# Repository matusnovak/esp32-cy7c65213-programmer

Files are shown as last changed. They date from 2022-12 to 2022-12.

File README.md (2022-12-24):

# ESP32 USB-C programmer with CY7C65213

This is a simple USB-C programmer that uses the CY7C65213 UART bridge controller. This repository contains KiCad 6 project files with gerber files exported. This board is capable of DTR and RTS, therefore the program upload experience should be without any problem.

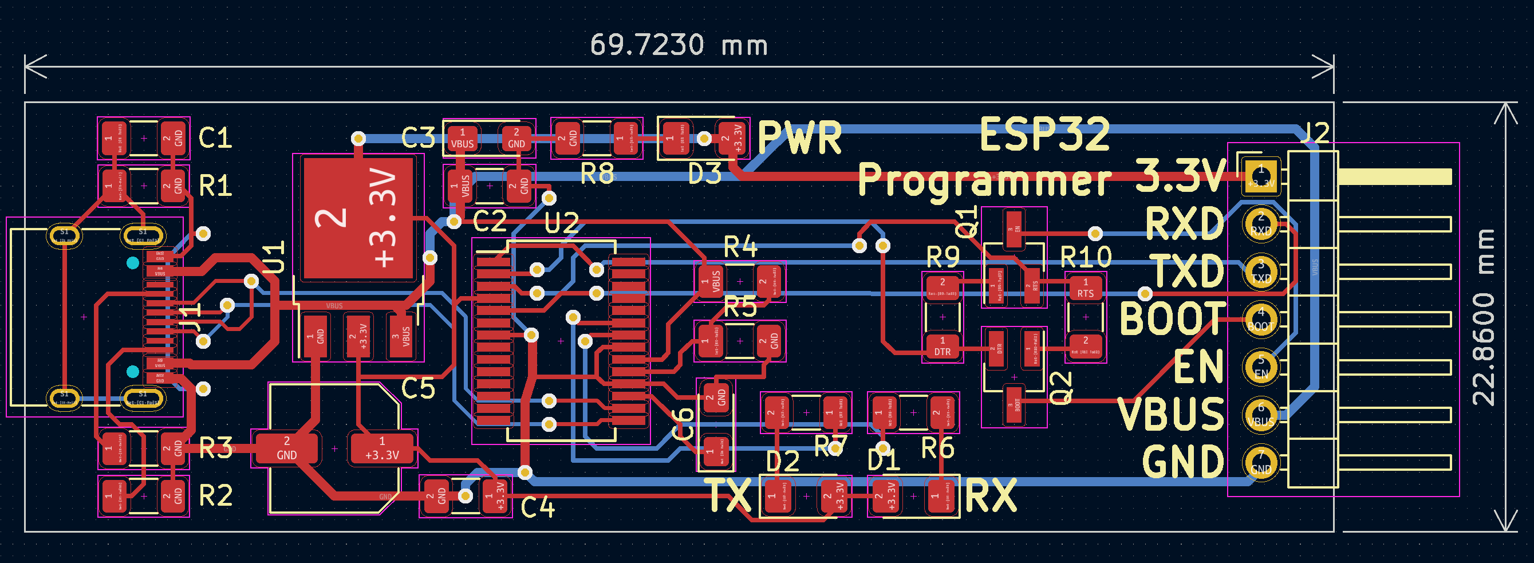
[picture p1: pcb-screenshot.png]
Board image


**[Schematic PDF](esp32-cy7c65213-programmer.pdf)**

## NOTE

* Do not connect a capacitor on the BOOT pin (GPIO 0 pin) towards the ground. It will cause the ESP32 to jump to the programming mode on power up.
* Use 1uF capacitor between the ESP32 reset pin (also known as EN or PN pin) between it and the ground. You will also need 10K pull-up resistor between that same reset pin and the + 3.3V.
* The Rx, Tx, Boot, and En pins on this board are 3.3V tolerant only.
* The Rx LED may start blinking or stay up. This is due to Rx picking up noise and treating it as a signal if nothing is connected to the Rx.

## Connection schematic

Use the following schematic to connect this programmer to ESP32

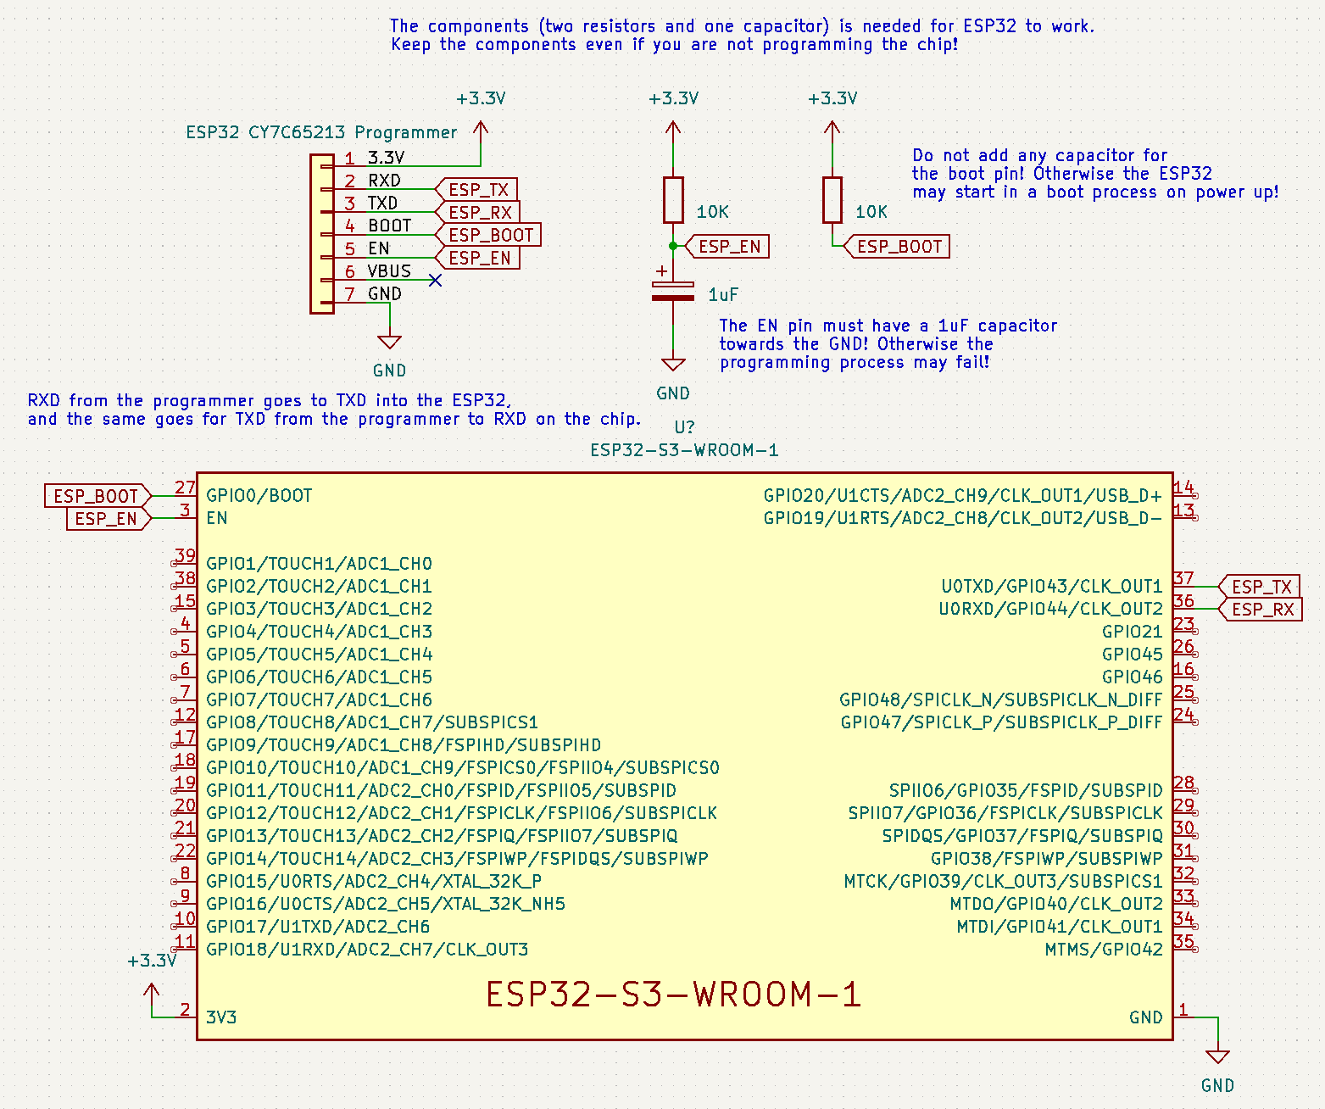
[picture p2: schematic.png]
schematic


## Drivers

* Windows: [Link to the manufacturer Infineon](https://www.infineon.com/cms/en/design-support/tools/sdk/usb-controllers-sdk/usb-serial-software-development-kit/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)
* Linux: Works out of the box, no driver needed, any recent Kernel is fine, it will appear at `/dev/ttyACM0`.
* MacOS: Should work out of the box.

## Why CY7C65213?

It works in Linux out of the box without the need to install any drivers (it needs a driver on Windows). Compared to the CH340 UART controller, the drivers for CY7C65213 are stable and mature. I do not want to install some shady CH340 drivers that work half of the time and randomly disconnect.

## Programming (platformio)

If you are using platformio for programming, you can use the following example below:

```ini
[env:esp32s3]
platform = espressif32        # Required
board = adafruit_feather_esp32s3_nopsram # Required, or choose similar
framework = espidf            # Or "arduino", your choice.
upload_port = /dev/ttyACM0    # Or COM3 or similar for Windows
board_build.flash_mode = dio  # Might be needed for a successful upload to ESP32-S3
monitor_port = /dev/ttyACM0   # Or COM3 or similar for Windows
monitor_speed = 115200        # This is the default value
```

## Programming (Arduino)

Simply choose the correct COM port from the top menu bar, and use the Adafruit Feather ESP32 board. (It should work with any board).

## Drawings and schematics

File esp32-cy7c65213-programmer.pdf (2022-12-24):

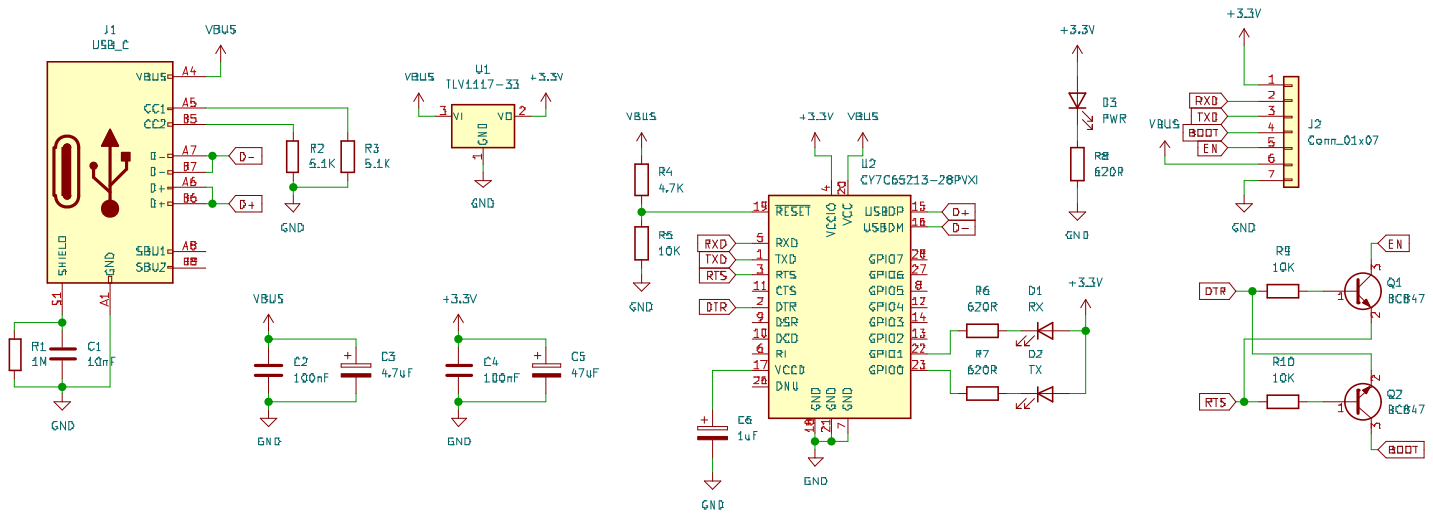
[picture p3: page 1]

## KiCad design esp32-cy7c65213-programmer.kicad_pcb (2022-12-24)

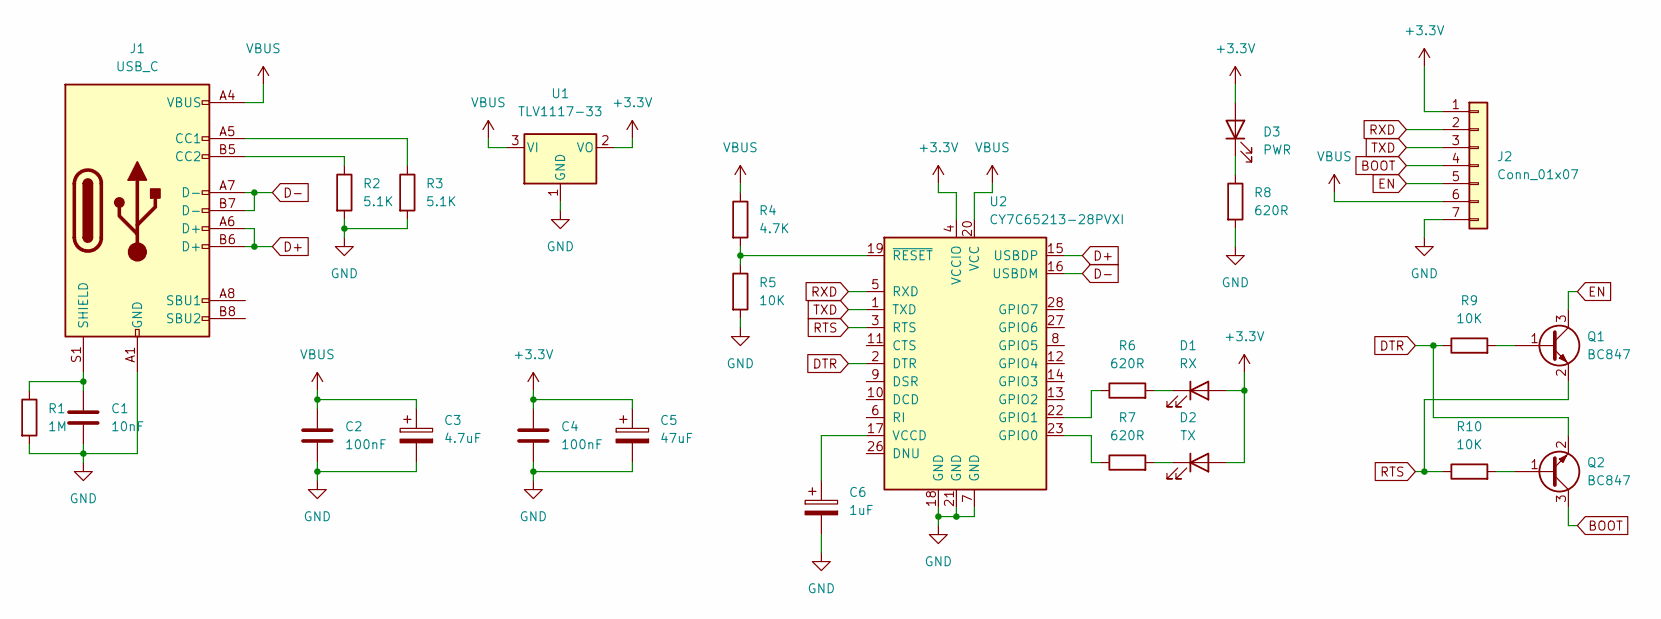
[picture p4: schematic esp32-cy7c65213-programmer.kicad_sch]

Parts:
C1: 10nF; C_1206_3216Metric_Pad1.33x1.80mm_HandSolder
C2, C4: 100nF; C_1206_3216Metric_Pad1.33x1.80mm_HandSolder
C3: 4.7uF; CP_EIA-3216-12_Kemet-S_Pad1.58x1.35mm_HandSolder
C5: 47uF; C_Elec_6.3x5.4
C6: 1uF; CP_EIA-3216-12_Kemet-S_Pad1.58x1.35mm_HandSolder
D1: RX; LED_1206_3216Metric_Pad1.42x1.75mm_HandSolder
D2: TX; LED_1206_3216Metric_Pad1.42x1.75mm_HandSolder
D3: PWR; LED_1206_3216Metric_Pad1.42x1.75mm_HandSolder
J1: USB_C; USB_C_Receptacle_HRO_TYPE-C-31-M-12
J2: Conn_01x07; PinHeader_1x07_P2.54mm_Horizontal
Q1, Q2: BC847; SOT-23_Handsoldering
R1: 1M; R_1206_3216Metric_Pad1.30x1.75mm_HandSolder
R2, R3: 5.1K; R_1206_3216Metric_Pad1.30x1.75mm_HandSolder
R4: 4.7K; R_1206_3216Metric_Pad1.30x1.75mm_HandSolder
R5, R9, R10: 10K; R_1206_3216Metric_Pad1.30x1.75mm_HandSolder
R6, R7, R8: 620R; R_1206_3216Metric_Pad1.30x1.75mm_HandSolder
U1: TLV1117-33; TO-252-3_TabPin2
U2: CY7C65213-28PVXI; SSOP-28_5.3x10.2mm_P0.65mm

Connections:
+3.3V: C4.1, C5.1, D1.2 (A), D2.2 (A), D3.2 (A), J2.1, U1.2 (VO), U2.4 (VCCIO)
BOOT: J2.4, Q2.3 (C)
D+: J1.A6 (D+), J1.B6 (D+), U2.15 (USBDP)
D-: J1.A7 (D-), J1.B7 (D-), U2.16 (USBDM)
DTR: Q2.2 (E), R9.1, U2.2 (DTR)
EN: J2.5, Q1.3 (C)
GND: C1.2, C2.2, C3.2, C4.2, C5.2, C6.2, J1.A1 (GND), J1.A12 (GND), J1.B1 (GND), J1.B12 (GND), J2.7, R1.2, R2.2, R3.2, R5.2, R8.2, U1.1 (GND), U2.7 (GND), U2.18 (GND), U2.21 (GND)
unnamed: C1.1, J1.S1 (SHIELD), R1.1
unnamed: C6.1, U2.17 (VCCD)
unnamed: D1.1 (K), R6.2
unnamed: D2.1 (K), R7.2
unnamed: D3.1 (K), R8.1
unnamed: J1.A5 (CC1), R3.1
unnamed: J1.B5 (CC2), R2.1
unnamed: R4.2, R5.1, U2.19 (~RESET)
unnamed: R6.1, U2.22 (GPIO1)
unnamed: R7.1, U2.23 (GPIO0)
unnamed: Q1.1 (B), R9.2
unnamed: Q2.1 (B), R10.2
RTS: Q1.2 (E), R10.1, U2.3 (RTS)
RXD: J2.2, U2.5 (RXD)
TXD: J2.3, U2.1 (TXD)
VBUS: C2.1, C3.1, J1.A4 (VBUS), J1.A9 (VBUS), J1.B4 (VBUS), J1.B9 (VBUS), J2.6, R4.1, U1.3 (VI), U2.20 (VCC)

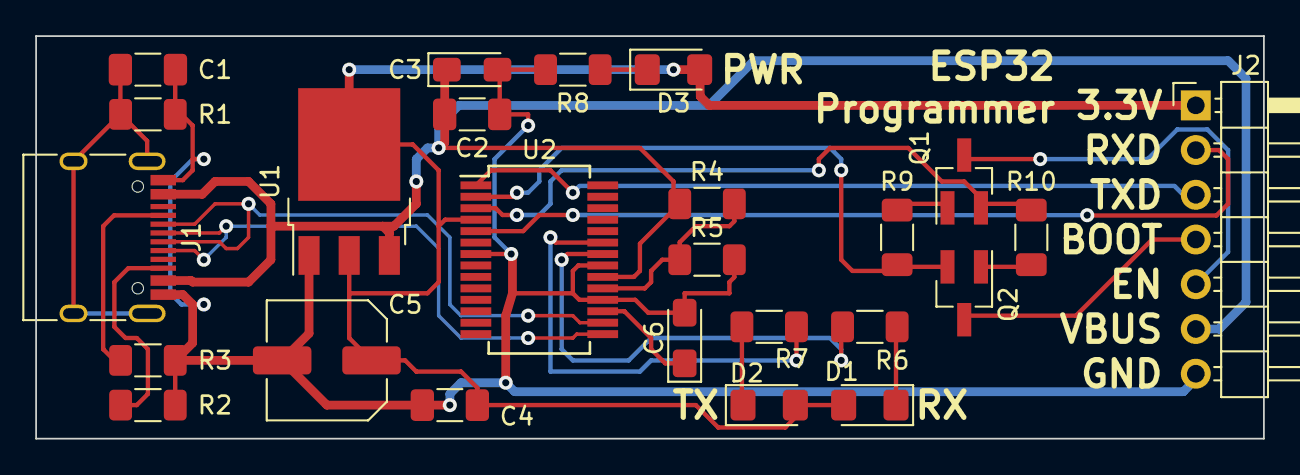
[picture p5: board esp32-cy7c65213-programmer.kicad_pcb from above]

Board: 2 copper layers, 69.7 x 22.9 mm, 25 parts (0 on the bottom side), 23 nets.

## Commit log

2022-11-25 Update readme with schematic and programming instructions
2022-11-25 Add schematic PDF
2022-12-24 Fix wrong transistor type and update the screenshots
    [esp32-cy7c65213-programmer-B_Cu.gbr, esp32-cy7c65213-programmer-B_Mask.gbr, esp32-cy7c65213-programmer-B_Paste.gbr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]
2022-12-24 Update the PDF with the latest schematic
